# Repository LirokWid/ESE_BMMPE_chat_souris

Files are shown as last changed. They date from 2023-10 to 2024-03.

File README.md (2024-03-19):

# ESE_BMMPE_chat_souris

Ce project a pour but de développer un robot qui joue à chat avec d'autres robots, il embarque un PCB custom avec un STM32G070. Le projet est développé avec freeRTOS.

Le pcb permet la connection de :
- 2 moteurs DC
- 2 encodeurs
- 1 module Bluetooth
- 1 lidar ydlidar x4
- 4 capteurs de touche
- 2 capteurs de vide
- 1 centrale inertielle

Membres :

- M PICHERY
- B RODIER
- M VAN DE MOOSDJIK
- P.-E. RETAUX

## Organisation du code

Le code fonctionne en modules contenus dans le dossier `drivers`.
Les dossiers sont organisés de la manière suivante :

- `CONTROL` :
Gère la logique de contrôle du robot. Il génère les signaux de commande pour les moteurs et les encodeurs.
- `HC-05` :
Api de communication avec le module Bluetooth HC-05.
- `IT` :
Gère les interruptions du microcontrôleur.
- `LIDAR` : 
Routine d'acquisition des données du lidar.
- `MOTOR` :
Gère les moteurs et les encodeurs.
- `MPU6050` :
Api de communication avec la centrale inertielle MPU6050.
- `PARAMS` :
Gère les paramètres du robot.
- `SYS_HELPER` :
Fonctions utilitaires pour le système.
- `UART` :
Fonctions de communication UART.

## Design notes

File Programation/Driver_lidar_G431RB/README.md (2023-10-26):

# YdlidarX4-stm32-driver
Simple driver to use a X4 lidar on an stm32 board (currently an STM32G431RB)

This code is part of a bigger project which uses a lidar on a robot to find enemies and play tag with them, you can find it [here](https://github.com/LirokWid/ESE_BMMPE_chat_souris)

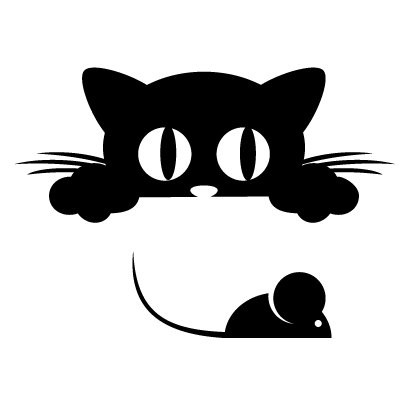
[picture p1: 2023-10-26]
KICAD/IMAGE_footprint/chat-souris.jpg

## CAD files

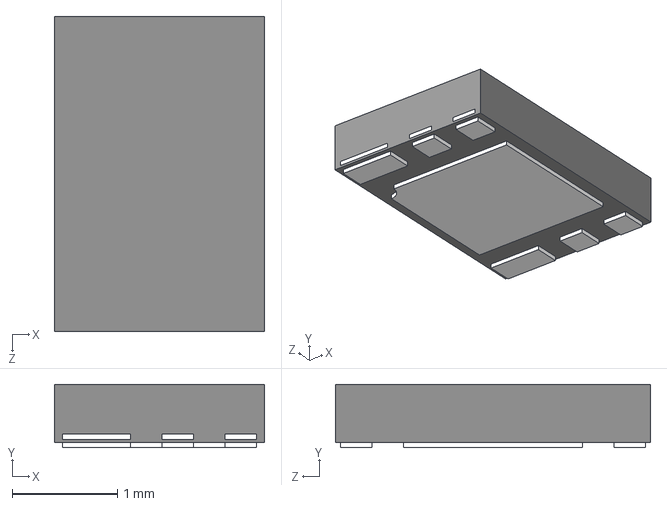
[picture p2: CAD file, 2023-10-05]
KICAD/PROTECT_AP9211SA-AK-HAC-7/AP9211SA-AK-HAC-7.step
2.00 x 0.6 x 3.00 mm

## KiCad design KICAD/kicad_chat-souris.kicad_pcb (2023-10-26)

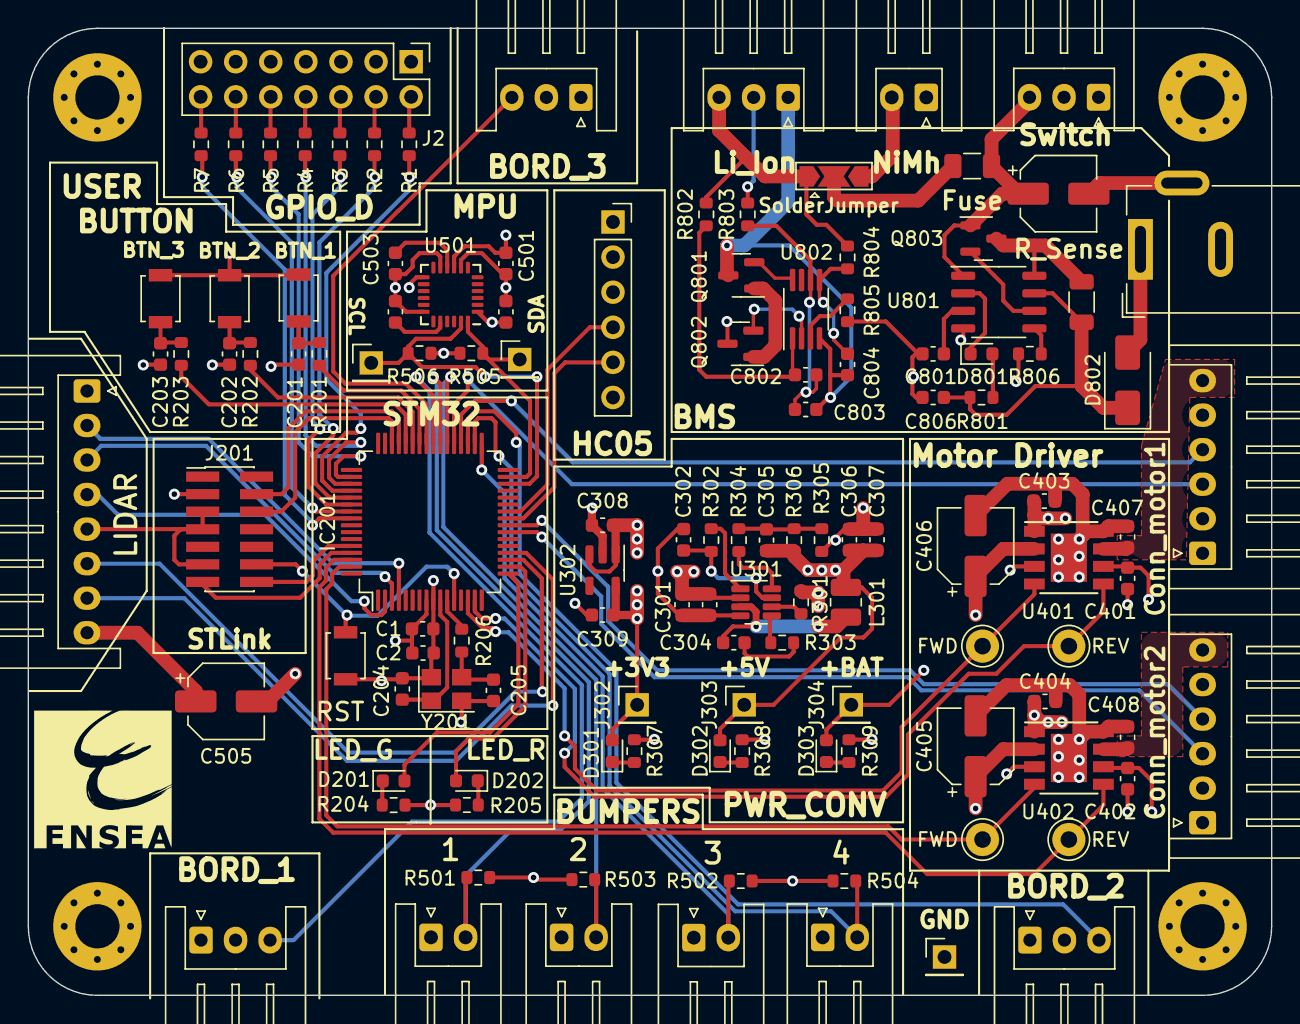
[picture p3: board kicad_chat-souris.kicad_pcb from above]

Board: 4 copper layers, 90.0 x 70.0 mm, 124 parts (1 on the bottom side), 98 nets.

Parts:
C1: 470n; C_0603_1608Metric
C2: 4.7µ; C_0603_1608Metric
C201, C202, C203, C302, C303, C304, C305, C503: 0.1uF; C_0603_1608Metric
C204, C205: 10pF; C_0603_1608Metric
C301, C306, C307: 22uF; C_0603_1608Metric
C308, C309, C401, C402: 1uF; C_0603_1608Metric
C403, C404, C407, C408: 47nF; C_0603_1608Metric
C405, C406: 10uF; CP_Elec_5x5.4
C501: 0.01nF; C_0603_1608Metric
C502: 0.01uF; C_0603_1608Metric
C504: 2.2nF; C_0603_1608Metric
C505: 4.7µ; CP_Elec_5x5.4
C801: 0.1µF; C_0603_1608Metric
C802, C803: 100n; C_0603_1608Metric
C804: 100nF; C_0603_1608Metric
C805: 10µ; CP_Elec_5x5.4
C806: 1µF; C_0603_1608Metric
D201: led_green; LED_0603_1608Metric
D202: led_red; LED_0603_1608Metric
D301, D302, D303: blue; LED_0603_1608Metric
D801: LED; LED_0603_1608Metric
D802: D_Schottky; D_SMA
F801: MF-NSML150/12-2; Fuse_1206_3216Metric
FWD: Pin_D1.0mm_L10.0mm_LooseFit
FWD#2: Pin_D1.0mm_L10.0mm_LooseFit
G1: LOGO; CHAT_SOURIE
IC201: STM32G070RBT6; LQFP-64_10x10mm_P0.5mm
J2: Conn_02x07_Counter_Clockwise; PinHeader_2x07_P2.54mm_Vertical
J201: ST/link connector; PinHeader_2x07_P1.27mm_Vertical_SMD
J301: power switch JST; JST_XH_S3B-XH-A_1x03_P2.50mm_Horizontal
J302: 3V3; PinHeader_1x01_P2.54mm_Vertical
J303: 5V; PinHeader_1x01_P2.54mm_Vertical
J304: V_BAT; PinHeader_1x01_P2.54mm_Vertical
J305: GND; PinHeader_1x01_P2.54mm_Vertical
J401: Conn_motor1; JST_XH_S6B-XH-A_1x06_P2.50mm_Horizontal
J402: Conn_motor2; JST_XH_S6B-XH-A_1x06_P2.50mm_Horizontal
J503: Conn_lidar; JST_XH_S8B-XH-A_1x08_P2.50mm_Horizontal
J504: Conn_Bmp_3; JST_XH_S2B-XH-A_1x02_P2.50mm_Horizontal
J505: Conn_Bmp_4; JST_XH_S2B-XH-A_1x02_P2.50mm_Horizontal
J506: SDA; PinHeader_1x01_P2.54mm_Vertical
J507: SCL; PinHeader_1x01_P2.54mm_Vertical
J601: Conn_bord1; JST_XH_S3B-XH-A_1x03_P2.50mm_Horizontal
J602: Conn_bord2; JST_XH_S3B-XH-A_1x03_P2.50mm_Horizontal
J801: 694102303002; BarrelJack_Wuerth_6941xx301002
J802: NiMH_Conn; JST_XH_S2B-XH-A_1x02_P2.50mm_Horizontal
J803: Li-Ion_Conn; JST_XH_S3B-XH-A_1x03_P2.50mm_Horizontal
JP801: SolderJumper; SolderJumper-3_P2.0mm_Open_TrianglePad1.0x1.5mm
L301: 4.7uH; L_1008_2520Metric
Q801, Q802: NMOS; SOT-23
Q803: PMOS; SOT-23
R1, R2, R3, R4, R5, R6, R7: R_Small; R_0603_1608Metric
R201, R202, R203: 20k; R_0603_1608Metric
R204: 5; R_0603_1608Metric
R205: 65; R_0603_1608Metric
R206: 10; R_0603_1608Metric
R301, R501, R502, R503, R504: 10k; R_0603_1608Metric
R302: 100k; R_0603_1608Metric
R303: 20; R_0603_1608Metric
R304: 16k; R_0603_1608Metric
R305: 7.68k; R_0603_1608Metric
R306: 40.2k; R_0603_1608Metric
R307, R802, R803, R804: 100; R_0603_1608Metric
R308: 50; R_0603_1608Metric
R309: 270; R_0603_1608Metric
R505, R506: 4.7k; R_0603_1608Metric
R801, R805: 2k; R_0603_1608Metric
R806: 19.6k; R_0603_1608Metric
REV: Pin_D1.0mm_L10.0mm_LooseFit
REV#2: Pin_D1.0mm_L10.0mm_LooseFit
R_SENSE801: 0.2; R_1206_3216Metric
SW201: RESET; SW_SPST_B3U-1000P
SW202: BTN_1; SW_SPST_B3U-1000P
SW203: BTN_2; SW_SPST_B3U-1000P
SW204: BTN_3; SW_SPST_B3U-1000P
U301: MP1475; SOT-23-8
U302: MIC5317-3.3v; SOT-23-5
U401: ZXBM5210-S_1; Diodes_SO-8EP
U402: ZXBM5210-S_2; Diodes_SO-8EP
U501: MPU-6050; InvenSense_QFN-24_4x4mm_P0.5mm
U701: PinSocket_1x06_P2.54mm_Vertical
U801: LTC1731ES8-8_4; SO-8_3.9x4.9mm_P1.27mm
U802: MSOP-8_3x3mm_P0.65mm
Y201: Crystal; Crystal_SMD_3225-4Pin_3.2x2.5mm
locked: Conn_Bmp_1; JST_XH_S2B-XH-A_1x02_P2.50mm_Horizontal
locked#2: Conn_Bmp_2; JST_XH_S2B-XH-A_1x02_P2.50mm_Horizontal
locked#3: Conn_bord3; JST_XH_S3B-XH-A_1x03_P2.50mm_Horizontal

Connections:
+3V3: C1.1, C2.1, C309.1, C401.1, C402.1, C501.1, C502.1, D301.2 (A), IC201.8 (VDD/VDDA), J201.3, J302.1, J401.5, J402.5, J601.2, J602.2, R501.2, R502.2, R503.2, R504.2, R505.2, R506.2, U302.5 (VOUT), U401.3 (VDD), U401.6 (VREF), U402.3 (VDD), U402.6 (VREF), U501.8 (VLOGIC), U501.13 (VDD), locked#3.2
+5V: C305.2, C306.1, C307.1, C308.1, C505.1, D302.2 (A), J303.1, J503.8, L301.2, R306.2, U302.1 (VIN), U302.3 (EN), U701.2 (Vcc(5v))
+BATT: C301.1, C303.1, C405.1, C406.1, D303.2 (A), J301.2, J304.1, R301.1, U301.2 (IN), U401.2 (VM), U402.2 (VM)
/Alimentation/BMS/Secu_Dout: Q801.2 (G), U802.8 (Dout)
/Alimentation/BMS/Secu_Sense: C804.1, R804.2, U802.5 (Sense)
/Alimentation/BMS/Secu_V-: R805.1, U802.3 (V-)
/Alimentation/BMS/Secu_VDD: C802.1, R802.1, U802.1 (VDD)
/Alimentation/BMS/Secu_Vc: C802.2, C803.1, R803.1, U802.6 (Vc)
/Alimentation/BMS/Secu_Vout: Q802.2 (G), U802.2 (Cout)
/Alimentation/BUCK_FB: R304.1, U301.8 (FB)
/Alimentation/BUCK_SW: C304.2, L301.1, U301.3 (SW)
/Drivers and motors connectors/ENCODER_1_A: IC201.37 (PA9), J401.3
/Drivers and motors connectors/ENCODER_1_B: IC201.36 (PA8), J401.4
/Drivers and motors connectors/ENCODER_2_A: IC201.23 (PA6), J402.3
/Drivers and motors connectors/ENCODER_2_B: IC201.24 (PA7), J402.4
/Drivers and motors connectors/MOT1_OUT1: C403.1, J401.1, U401.1 (OUT1)
/Drivers and motors connectors/MOT1_OUT2: C407.1, J401.6, U401.7 (OUT2)
/Drivers and motors connectors/MOT2_OUT1: C404.1, J402.1, U402.1 (OUT1)
/Drivers and motors connectors/MOT2_OUT2: C408.1, J402.6, U402.7 (OUT2)
/Drivers and motors connectors/MOTOR_1_FWD: FWD#2.1, IC201.14 (PC1), U401.4 (FWD)
/Drivers and motors connectors/MOTOR_1_REV: IC201.15 (PC2), REV#2.1, U401.5 (REV)
/Drivers and motors connectors/MOTOR_2_FWD: FWD.1, IC201.63 (PB9), U402.4 (FWD)
/Drivers and motors connectors/MOTOR_2_REV: IC201.62 (PB8), REV.1, U402.5 (REV)
/STM32/BTN_1: IC201.42 (PA10), R201.1
/STM32/BTN_2: IC201.43 (PA11_[PA9]), R202.1
/STM32/BTN_3: IC201.44 (PA12_[PA10]), R203.1
/STM32/Bordure_1: IC201.40 (PD8), J601.3
/STM32/Bordure_2: IC201.41 (PD9), J602.3
/STM32/Bordure_3: IC201.35 (PB15), locked#3.3
/STM32/Bumper_1: IC201.39 (PC7), R501.1, locked.2
/STM32/Bumper_2: IC201.38 (PC6), J504.2, R503.1
/STM32/Bumper_3: IC201.33 (PB13), R502.1, locked#2.2
/STM32/Bumper_4: IC201.34 (PB14), J505.2, R504.1
/STM32/I2C_SCL: IC201.30 (PB10), J507.1, R506.1, U501.23 (SCL)
/STM32/I2C_SDA: IC201.31 (PB11), J506.1, R505.1, U501.24 (SDA)
/STM32/LIDAR_MESURE_ENABLE: IC201.3 (PC13), J503.3
/STM32/LIDAR_MOTOR_ENABLE: IC201.4 (PC14-OSC32_IN), J503.2
/STM32/LIDAR_PWM: IC201.2 (PC12), J503.4
/STM32/NRST: IC201.12 (NRST), J201.12, SW201.2 (B)
/STM32/OSC_IN: C204.1, IC201.10 (PF0-OSC_IN), Y201.1
/STM32/OSC_OUT: IC201.11 (PF1-OSC_OUT), R206.1
/STM32/PD0: IC201.50 (PD0), R5.1
/STM32/PD1: IC201.51 (PD1), R4.1
/STM32/PD2: IC201.52 (PD2), R1.1
/STM32/PD3: IC201.53 (PD3), R2.1
/STM32/PD4: IC201.54 (PD4), R3.1
/STM32/PD5: IC201.55 (PD5), R6.1
/STM32/PD6: IC201.56 (PD6), R7.1
/STM32/SWCLK: IC201.46 (PA14-BOOT0), J201.6
/STM32/SWDIO: IC201.45 (PA13), J201.4
/STM32/USART1_RX: IC201.61 (PB7), J201.13
/STM32/USART1_TX: IC201.60 (PB6), J201.14
/STM32/USART2_RX: IC201.20 (PA3), J503.7
/STM32/USART2_TX: IC201.19 (PA2), J503.6
/STM32/USART3_RX: IC201.26 (PC5), U701.4 (Tx)
/STM32/USART3_TX: IC201.25 (PC4), U701.5 (Rx)
BAT+: C805.1, F801.1, J301.3, Q803.1 (D), U801.1 (BAT)
GND: C1.2, C2.2, C201.2, C202.2, C203.2, C204.2, C205.2, C301.2, C302.2, C303.2, C306.2, C307.2, C308.2, C309.2, C401.2, C402.2, C403.2, C404.2, C405.2, C406.2, C407.2, C408.2, C501.2, C502.2, C503.2, C504.2, C505.2, C801.2, C805.2, C806.2, IC201.9 (VSS/VSSA), J2.1, J2.3, J2.5, J2.7, J2.9, J2.11, J2.13, J201.5, J201.7, J201.11, J305.1, J401.2, J402.2, J503.5, J504.1, J505.1, J601.1, J602.1, J801.2, J801.3, J802.1, Q802.3 (S), R204.2, R205.1, R305.1, R307.2, R308.2, R309.2, R805.2, R806.2, SW201.1 (A), SW202.1 (A), SW203.1 (A), SW204.1 (A), U301.4 (GND), U302.2 (GND), U401.8 (GND), U401.9 (GND), U402.8 (GND), U402.9 (GND), U501.1 (CLKIN), U501.9 (AD0), U501.11 (FSYNC), U501.18 (GND), U701.3 (GND), U801.4 (GND), Y201.2, Y201.4, locked.1, locked#2.1, locked#3.1
Li_Ion+: J803.3, JP801.1 (A), R802.2, R804.1
Li_Ion-: C803.2, C804.2, J803.1, Q801.3 (S), U802.4 (VSS)
Li_Ion_INTER: J803.2, R803.2
unnamed: C205.1, R206.2, Y201.3
unnamed: C304.1, R303.2
unnamed: C305.1, R304.2, R305.2, R306.1
unnamed: D201.2 (A), IC201.17 (PA0)
unnamed: D201.1 (K), R204.1
unnamed: D202.2 (A), IC201.18 (PA1)
unnamed: D202.1 (K), R205.2
unnamed: D301.1 (K), R307.1
unnamed: D302.1 (K), R308.1
unnamed: D303.1 (K), R309.1
unnamed: D801.2 (A), R801.2
unnamed: D801.1 (K), U801.2 (*CHRG)
unnamed: C806.1, D802.1 (K), R801.1, R_SENSE801.1, U801.7 (VCC)
unnamed: J2.2, R1.2
unnamed: J2.4, R2.2
unnamed: J2.6, R3.2
unnamed: J2.8, R4.2
unnamed: J2.10, R5.2
unnamed: J2.12, R6.2
unnamed: J2.14, R7.2
unnamed: F801.2, JP801.2 (C)
unnamed: Q801.1 (D), Q802.1 (D)
unnamed: Q803.2 (G), U801.6 (DRV)
unnamed: Q803.3 (S), R_SENSE801.2, U801.8 (SENSE)
unnamed: C201.1, R201.2, SW202.2 (B)
unnamed: C202.1, R202.2, SW203.2 (B)
unnamed: C203.1, R203.2, SW204.2 (B)
unnamed: R303.1, U301.5 (BST)
unnamed: R301.2, U301.6 (EN/SYNC)
unnamed: R302.2, U301.1 (PG)
unnamed: C302.1, R302.1, U301.7 (VCC)
unnamed: C504.1, U501.20 (CPOUT)
unnamed: C503.1, U501.10 (REGOUT)
unnamed: R806.1, U801.5 (PROG)
unnamed: C801.1, U801.3 (TIMER)
NiMh+: J802.2, JP801.3 (B)
V_ALIM: D802.2 (A), J801.1

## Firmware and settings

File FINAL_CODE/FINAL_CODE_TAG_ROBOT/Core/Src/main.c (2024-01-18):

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
/* Includes ------------------------------------------------------------------*/
#include "main.h"
#include "cmsis_os.h"
#include "dma.h"
#include "i2c.h"
#include "tim.h"
#include "usart.h"
#include "gpio.h"

/* USER CODE BEGIN Includes */
#include "../../Drivers/UART/transmit_uart.h"
#include "../../Drivers/LIDAR/lidar_task.h"
#include "../../Drivers/SYS_HELPER/sys_helper_task.h"
#include "../../Drivers/IT/capt_btn.h"
#include "../../Drivers/CONTROL/robot_control_task.h"
#include "../../Drivers/HC05/HC05_task.h"
#include "../../Drivers/PARAMS/params.h"
#include "../../Drivers/MPU6050/mpu6050_task.h"
/* USER CODE END Includes */


void SystemClock_Config(void);
void MX_FREERTOS_Init(void);
/* USER CODE BEGIN 0 */
void Init_system(){
	printf("Init System..\r\n");
}

void vApplicationStackOverflowHook( TaskHandle_t xTask,signed char *pcTaskName ){
	printf("Task %s overflowed !",pcTaskName);
}

/* USER CODE END 0 */

/**
  * @brief  The application entry point.
  * @retval int
  */
int main(void)
{
  /* MCU Configuration--------------------------------------------------------*/

  /* Reset of all peripherals, Initializes the Flash interface and the Systick. */
  HAL_Init();

  /* Configure the system clock */
  SystemClock_Config();

  /* Initialize all configured peripherals */
  MX_GPIO_Init();
  MX_DMA_Init();
  MX_I2C2_Init();
  MX_TIM1_Init();
  MX_TIM3_Init();
  MX_TIM6_Init();
  MX_TIM7_Init();
  MX_TIM16_Init();
  MX_TIM17_Init();
  MX_USART1_UART_Init();
  MX_USART3_UART_Init();
  MX_USART2_UART_Init();
  MX_TIM15_Init();
  /* USER CODE BEGIN 2 */
  Init_system();
  // Create all custom FreeRTOS tasks

  portDISABLE_INTERRUPTS();
  Init_lidar(15,&huart2);
#ifdef LOG_LIDAR
  create_sys_task(20);
#endif
  capt_btn_init(25);
  robot_control_init(11);
  portENABLE_INTERRUPTS();


  printf("!!!!starting scheduler!!!!\r\n");
  // Start the scheduler and tasks
  vTaskStartScheduler();

  /* USER CODE END 2 */

  /* Call init function for freertos objects (in freertos.c) */
  MX_FREERTOS_Init();

  /* Start scheduler */
  osKernelStart();

  /* We should never get here as control is now taken by the scheduler */
  /* Infinite loop */
  /* USER CODE BEGIN WHILE */
  while (1)
  {
    /* USER CODE END WHILE */

    /* USER CODE BEGIN 3 */
  }
  /* USER CODE END 3 */
}

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
/**
  * @brief  Period elapsed callback in non blocking mode
  * @note   This function is called  when TIM14 interrupt took place, inside
  * HAL_TIM_IRQHandler(). It makes a direct call to HAL_IncTick() to increment
  * a global variable "uwTick" used as application time base.
  * @param  htim : TIM handle
  * @retval None
  */
void HAL_TIM_PeriodElapsedCallback(TIM_HandleTypeDef *htim)
{
  if (htim->Instance == TIM14) {
    HAL_IncTick();
  }
}

/**
  * @brief  This function is executed in case of error occurrence.
  * @retval None
  */
void Error_Handler(void)
{
  /* USER CODE BEGIN Error_Handler_Debug */
  /* User can add his own implementation to report the HAL error return state */
	HAL_GPIO_WritePin(LED_ERROR_GPIO_Port, LED_ERROR_Pin, SET);
	__disable_irq();
  while (1)
  {
  }
  /* USER CODE END Error_Handler_Debug */
}

#ifdef  USE_FULL_ASSERT
/**
  * @brief  Reports the name of the source file and the source line number
  *         where the assert_param error has occurred.
  * @param  file: pointer to the source file name
  * @param  line: assert_param error line source number
  * @retval None
  */
void assert_failed(uint8_t *file, uint32_t line)
{
  /* USER CODE BEGIN 6 */
  /* User can add his own implementation to report the file name and line number,
     ex: printf("Wrong parameters value: file %s on line %d\r\n", file, line) */
  /* USER CODE END 6 */
}
#endif /* USE_FULL_ASSERT */

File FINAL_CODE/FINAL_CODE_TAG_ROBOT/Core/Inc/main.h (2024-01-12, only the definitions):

#define LIDAR_MOTOR_PWM_Pin GPIO_PIN_12
#define LIDAR_MOTOR_PWM_GPIO_Port GPIOC
#define LIDAR_MOTOR_ENABLE_Pin GPIO_PIN_13
#define LIDAR_MOTOR_ENABLE_GPIO_Port GPIOC
#define LIDAR_MESURE_ENABLE_Pin GPIO_PIN_14
#define LIDAR_MESURE_ENABLE_GPIO_Port GPIOC
#define MOTOR_1_FWD_Pin GPIO_PIN_1
#define MOTOR_1_FWD_GPIO_Port GPIOC
#define MOTOR_1_REV_Pin GPIO_PIN_2
#define MOTOR_1_REV_GPIO_Port GPIOC
#define LED_STATE_Pin GPIO_PIN_0
#define LED_STATE_GPIO_Port GPIOA
#define LED_ERROR_Pin GPIO_PIN_1
#define LED_ERROR_GPIO_Port GPIOA
#define ENCODER_2_A_Pin GPIO_PIN_6
#define ENCODER_2_A_GPIO_Port GPIOA
#define ENCODER_2_B_Pin GPIO_PIN_7
#define ENCODER_2_B_GPIO_Port GPIOA
#define BUMPER_3_Pin GPIO_PIN_13
#define BUMPER_3_GPIO_Port GPIOB
#define BUMPER_3_EXTI_IRQn EXTI4_15_IRQn
#define BUMPER_4_Pin GPIO_PIN_14
#define BUMPER_4_GPIO_Port GPIOB
#define BUMPER_4_EXTI_IRQn EXTI4_15_IRQn
#define ENCODER_1_B_Pin GPIO_PIN_8
#define ENCODER_1_B_GPIO_Port GPIOA
#define ENCODER_1_A_Pin GPIO_PIN_9
#define ENCODER_1_A_GPIO_Port GPIOA
#define BUMPER_2_Pin GPIO_PIN_6
#define BUMPER_2_GPIO_Port GPIOC
#define BUMPER_2_EXTI_IRQn EXTI4_15_IRQn
#define BUMPER_1_Pin GPIO_PIN_7
#define BUMPER_1_GPIO_Port GPIOC
#define BUMPER_1_EXTI_IRQn EXTI4_15_IRQn
#define BORDURE_1_Pin GPIO_PIN_8
#define BORDURE_1_GPIO_Port GPIOD
#define BORDURE_1_EXTI_IRQn EXTI4_15_IRQn
#define BORDURE_2_Pin GPIO_PIN_9
#define BORDURE_2_GPIO_Port GPIOD
#define BORDURE_2_EXTI_IRQn EXTI4_15_IRQn
#define BTN_1_Pin GPIO_PIN_10
#define BTN_1_GPIO_Port GPIOA
#define BTN_1_EXTI_IRQn EXTI4_15_IRQn
#define BTN_2_Pin GPIO_PIN_11
#define BTN_2_GPIO_Port GPIOA
#define BTN_2_EXTI_IRQn EXTI4_15_IRQn
#define BTN_3_Pin GPIO_PIN_12
#define BTN_3_GPIO_Port GPIOA
#define BTN_3_EXTI_IRQn EXTI4_15_IRQn
#define LED_3_Pin GPIO_PIN_0
#define LED_3_GPIO_Port GPIOD
#define LED_2_Pin GPIO_PIN_5
#define LED_2_GPIO_Port GPIOD
#define LED_1_Pin GPIO_PIN_6
#define LED_1_GPIO_Port GPIOD
#define MOTOR_2_REV_Pin GPIO_PIN_8
#define MOTOR_2_REV_GPIO_Port GPIOB
#define MOTOR_2_FWD_Pin GPIO_PIN_9
#define MOTOR_2_FWD_GPIO_Port GPIOB

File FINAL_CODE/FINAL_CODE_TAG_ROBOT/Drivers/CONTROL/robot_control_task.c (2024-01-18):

/**
 * @file robot_control_task.c
 * @brief Implementation file for robot control task.
 */

#include "robot_control_task.h"

TaskHandle_t TaskHandle_robot_ctrl;

extern h_lidar_t lidar;

robot_state_t robot;

int robot_control_init(int task_priority)
{
    BaseType_t xReturned;

    printf("Loading robot control task with priority %d\n\r", task_priority);
    xReturned = xTaskCreate(
        robot_control_Task,
        "rbt_ctrl_Task",
        500,
        NULL,
        task_priority,
        &TaskHandle_robot_ctrl);

    if (xReturned == pdPASS) {
        printf("Task loaded\r\n");
        return 0;
    } else {
        printf("Error loading task\r\n");
        return 1;
    }
}

void robot_control_Task(void *unused)
{
    printf("Starting robot_control task\r\n");
    vTaskDelay(pdMS_TO_TICKS(500));

    if (!lidar.is_sending)
	{//Reset the ucontroler until the lidar start
        HAL_NVIC_SystemReset();
    }

    motor_t L_motor;
    motor_t R_motor;
    init_motors(&L_motor, &R_motor);

    robot.mode = IDLE;
    robot.type = STARTING_MODE;

    for (;;) {
        HAL_GPIO_TogglePin(LED_1_GPIO_Port, LED_1_Pin); // See refresh rate on a led

        if (robot.type == MOUSE) {
            HAL_GPIO_WritePin(LED_ERROR_GPIO_Port, LED_ERROR_Pin, SET);
        } else {
            HAL_GPIO_WritePin(LED_ERROR_GPIO_Port, LED_ERROR_Pin, RESET);
        }

        switch (robot.mode) {
        case IDLE:
            standby_mode(&L_motor);
            standby_mode(&R_motor);
            break;
        case TRACKING:
            if (robot.type == CAT) {
                hunt_enemy(&L_motor, &R_motor);
            } else {
                avoid_enemy(&L_motor, &R_motor);
            }
            break;
        case AVOID_EDGE:
            control_set_speed(-AVOID_BACKWARD_SPEED, &L_motor, &R_motor);
            vTaskDelay(pdMS_TO_TICKS(AVOID_BACKWARD_TIME));
            control_set_rotate(AVOID_ROTATION_SPEED, &L_motor, &R_motor);
            vTaskDelay(pdMS_TO_TICKS(AVOID_ROTATION_TIME));
            standby_mode(&L_motor);
            standby_mode(&R_motor);

            robot.mode = TRACKING;
            break;
        case PUSH_BACK:
            control_set_speed(-AVOID_BACKWARD_SPEED, &L_motor, &R_motor);
            vTaskDelay(pdMS_TO_TICKS(AVOID_BACKWARD_TIME));
            standby_mode(&L_motor);
            standby_mode(&R_motor);
            vTaskDelay(pdMS_TO_TICKS(1000));
            robot.mode = TRACKING;
            break;
        }

        vTaskDelay(pdMS_TO_TICKS(50)); // Run at 20 Hz
    }
}

void control_set_speed_line_rotate(int16_t command, motor_t *L_motor, motor_t *R_motor)
{
#ifdef USE_MOTORS
    int16_t speed_L, speed_R;

    speed_L = constrain(command + FORWARD_SPEED, MAX_SPEED_FWD, -MAX_SPEED_REV);
    speed_R = constrain(-command + FORWARD_SPEED, MAX_SPEED_FWD, -MAX_SPEED_REV);
    set_speed(speed_L, L_motor);
    set_speed(speed_R, R_motor);
#endif
}

void control_set_rotate(int16_t command, motor_t *L_motor, motor_t *R_motor)
{
#ifdef USE_MOTORS
    set_speed(command, L_motor);
    set_speed(-command, R_motor);
#endif
}

void control_set_speed_line(int16_t command, motor_t *L_motor, motor_t *R_motor)
{
#ifdef USE_MOTORS
    int16_t speed;
    speed = constrain(command, MAX_SPEED_FWD, -MAX_SPEED_REV);
    set_speed(speed, L_motor);
    set_speed(-speed, R_motor);
#endif
}

void control_set_speed(int16_t command, motor_t *L_motor, motor_t *R_motor)
{
#ifdef USE_MOTORS
    int16_t speed;
    speed = command;
    set_speed(speed, L_motor);
    set_speed(speed, R_motor);
#endif
}

int16_t constrain(int16_t value, int8_t max, int8_t min)
{
    if (value < min) {
        return min;
    }
    if (value > max) {
        return max;
    }
    return value;
}

int16_t get_oposite_angle_360(int16_t angle)
{
    angle += 180;
    if (angle > 360) {
        return angle - 360;
    } else {
        return angle;
    }
}

void hunt_enemy(motor_t *L_motor, motor_t *R_motor)
{
    uint16_t angle = lidar.target.angle;
    int16_t angle_diff;

    angle_diff = map_360_0_to_100_min100(angle);
    int16_t command = attenuate(angle_diff);
    control_set_speed_line_rotate(constrain(command, MAX_ROTATION_SPEED, -MAX_ROTATION_SPEED), L_motor, R_motor);
}

uint16_t attenuate(uint16_t command)
{
    if (abs(command) < 90 && abs(command) > 45) {
        return (command * 3) / 2;
    }
    if (abs(command) <= 45) {
        return command / 2;
    }
    return command;
}

void avoid_enemy(motor_t *L_motor, motor_t *R_motor)
{
    uint16_t angle = get_oposite_angle_360(lidar.target.angle);
    int16_t angle_diff;
    angle_diff = map_360_0_to_100_min100(angle);
    int16_t command = attenuate(angle_diff);
    control_set_speed_line_rotate(constrain(command, MAX_ROTATION_SPEED, -MAX_ROTATION_SPEED), L_motor, R_motor);
}

int16_t map_360_0_to_100_min100(int16_t x)
{
    int16_t temp_val;
    if (x >= 0 && x < 180) {
        temp_val = x;
    } else {
        temp_val = x - 360;
    }

    const int16_t in_min = -180;
    const int16_t in_max = 180;
    const int16_t out_min = -100;
    const int16_t out_max = 100;

    return (temp_val - in_min) * (out_max - out_min) / (in_max - in_min) + out_min;
}

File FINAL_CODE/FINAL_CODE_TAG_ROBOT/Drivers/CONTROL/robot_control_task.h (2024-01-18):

/**
 * @file robot_control_task.h
 * @brief Header file for robot control task.
 */

#ifndef ROBOT_CONTROL_TASK_H
#define ROBOT_CONTROL_TASK_H

#include <stdlib.h>

#include "../MOTOR/motor_driver.h"
#include "../UART/printf_uart.h"
#include "../LIDAR/lidar_driver.h"
#include "cmsis_os.h"

/**
 * @def PRINTF_DEBUG
 * @brief Debug flag for printf.
 */
#define PRINTF_DEBUG

/**
 * @def USE_MOTORS
 * @brief Enable/disable motor control.
 */
#define USE_MOTORS
//#define HOLD_POSITION

/**
 * @def STARTING_MODE
 * @brief Default starting mode for the robot.
 */
#define STARTING_MODE CAT

/**
 * @def DELAY_UNTIL_MOTOR_START
 * @brief Delay until motor start in milliseconds.
 */
#define DELAY_UNTIL_MOTOR_START 3000

/**
 * @def MAX_SPEED_FWD
 * @brief Maximum forward speed for the robot.
 */
#define MAX_SPEED_FWD 75

/**
 * @def MAX_SPEED_REV
 * @brief Maximum reverse speed for the robot.
 */
#define MAX_SPEED_REV 60

#ifdef HOLD_POSITION
#define FORWARD_SPEED 0
#else
#define FORWARD_SPEED 60
#endif

/**
 * @def MAX_ROTATION_SPEED
 * @brief Maximum rotation speed for the robot.
 */
#define MAX_ROTATION_SPEED 40

/**
 * @def AVOID_BACKWARD_SPEED
 * @brief Speed used during backward movement for obstacle avoidance.
 */
#define AVOID_BACKWARD_SPEED 40

/**
 * @def AVOID_BACKWARD_TIME
 * @brief Time for backward movement during obstacle avoidance in milliseconds.
 */
#define AVOID_BACKWARD_TIME  400

/**
 * @def AVOID_ROTATION_SPEED
 * @brief Rotation speed during obstacle avoidance.
 */
#define AVOID_ROTATION_SPEED 70

/**
 * @def AVOID_ROTATION_TIME
 * @brief Time for rotation during obstacle avoidance in milliseconds.
 */
#define AVOID_ROTATION_TIME  700

/**
 * @def time_ms_backward
 * @brief Time for backward movement in milliseconds.
 */
#define time_ms_backward 400

/**
 * @enum type_t
 * @brief Enumeration for robot types.
 */
typedef enum type {
    CAT,  /**< Cat type. */
    MOUSE /**< Mouse type. */
} type_t;

/**
 * @enum robot_mode_t
 * @brief Enumeration for robot modes.
 */
typedef enum robot_mode {
    IDLE,          /**< Idle mode. */
    TRACKING,      /**< Tracking mode. */
    AVOID_EDGE,    /**< Avoid edge mode. */
    PUSH_BACK      /**< Push back mode. */
} robot_mode_t;

/**
 * @struct robot_state_t
 * @brief Structure representing the state of the robot.
 */
typedef struct robot_state {
    type_t        type; /**< Type of the robot. */
    robot_mode_t  mode; /**< Mode of the robot. */
} robot_state_t;

/**
 * @brief Constrain a value within a specified range.
 * @param value The value to be constrained.
 * @param max The maximum allowed value.
 * @param min The minimum allowed value.
 * @return The constrained value.
 */
int16_t constrain(int16_t value, int8_t max, int8_t min);

/**
 * @brief Map a 360-degree angle to a range from 0 to 100, with a minimum of -100.
 * @param x The input angle.
 * @return The mapped value.
 */
int16_t map_360_0_to_100_min100(int16_t x);

/**
 * @brief Get the opposite angle in the 360-degree range.
 * @param angle The input angle.
 * @return The opposite angle.
 */
int16_t get_oposite_angle_360(int16_t angle);

/**
 * @brief Initialize the robot control task.
 * @param task_priority Priority of the task.
 * @return 0 if successful, 1 if there is an error.
 */
int robot_control_init(int task_priority);

/**
 * @brief Robot control task function.
 * @param unused Unused parameter.
 */
void robot_control_Task(void *unused);

/**
 * @brief Hunt the enemy based on LIDAR readings.
 * @param L_motor Pointer to the left motor.
 * @param R_motor Pointer to the right motor.
 */
void hunt_enemy(motor_t *L_motor, motor_t *R_motor);

/**
 * @brief Attenuate the command based on angle difference.
 * @param command The command to be attenuated.
 * @return The attenuated command.
 */
uint16_t attenuate(uint16_t command);

/**
 * @brief Avoid the enemy based on LIDAR readings.
 * @param L_motor Pointer to the left motor.
 * @param R_motor Pointer to the right motor.
 */
void avoid_enemy(motor_t *L_motor, motor_t *R_motor);

/**
 * @brief Set the robot to rotate at a specified speed.
 * @param command The rotation speed command.
 * @param L_motor Pointer to the left motor.
 * @param R_motor Pointer to the right motor.
 */
void control_set_rotate(int16_t command, motor_t *L_motor, motor_t *R_motor);

/**
 * @brief Set the robot to move with speed and rotation.
 * @param command The movement command.
 * @param L_motor Pointer to the left motor.
 * @param R_motor Pointer to the right motor.
 */
void control_set_speed_line_rotate(int16_t command, motor_t *L_motor, motor_t *R_motor);

/**
 * @brief Set the robot to move in a straight line with a specified speed.
 * @param command The movement command.
 * @param L_motor Pointer to the left motor.
 * @param R_motor Pointer to the right motor.
 */
void control_set_speed_line(int16_t command, motor_t *L_motor, motor_t *R_motor);

/**
 * @brief Set the robot to move with a specified speed.
 * @param command The movement command.
 * @param L_motor Pointer to the left motor.
 * @param R_motor Pointer to the right motor.
 */
void control_set_speed(int16_t command, motor_t *L_motor, motor_t *R_motor);

#endif

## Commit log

2023-09-25 Kicad first rev schematics
    [Capteur de bordure.kicad_sch, STM32.kicad_sch, alimentation.kicad_sch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]
2023-09-28 update file structure
    [Capteur de bordure.kicad_sch, STM32.kicad_sch, alimentation.kicad_sch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]
2023-09-28 update schematics
    [Capteur de bordure.kicad_sch, STM32.kicad_sch, alimentation.kicad_sch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]
2023-10-05 Completed schematics
    [AP9211SA-AK-HAC-7.step, Capteur de bordure.kicad_sch, STM32.kicad_sch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]
2023-10-05 update polarity connectors
    [bms.kicad_sch]
2023-10-05 lidar driver project added
    [kicad_chat-souris.kicad_pcb, kicad_chat-souris.kicad_sch]
2023-10-26 PCB finalized
    [Capteur de bordure.kicad_sch, STM32.kicad_sch, alimentation.kicad_sch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]
2024-01-07 Lidar tracking works
2024-01-07 added processing 2d render of lidar data

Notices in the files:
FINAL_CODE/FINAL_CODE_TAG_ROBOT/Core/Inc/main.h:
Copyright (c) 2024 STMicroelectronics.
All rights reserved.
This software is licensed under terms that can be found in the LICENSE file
